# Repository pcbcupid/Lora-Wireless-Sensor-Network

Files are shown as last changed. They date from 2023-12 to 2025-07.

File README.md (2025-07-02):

# Lora-Wireless-Sensor-Network



This repo will teach you, how to build a hardware product based on WSN completely from scratch!

We'll walk you through all the stages : 
* [Purpose](https://www.youtube.com/watch?v=e1ifblb0CRQ)
* [Brainstroming -> Feature Selection](https://www.youtube.com/watch?v=0gfi7CeLzbg)
* [Features -> Component Selection](https://youtu.be/0gfi7CeLzbg?t=293)
* [Component -> Schematic Design](https://www.youtube.com/watch?v=nbiwXsXPYxc)
* [Schematic Design -> PCB Design](https://www.youtube.com/watch?v=FiMsBjr6rtk)
* [PCB -> Mechanical Case Design](https://youtu.be/7FC-pByCCXM?si=cBypyLcrKBF-iJE6)
* [Finished Hardware + Code](https://github.com/pcbcupid/Lora-Wireless-Sensor-Network/tree/main/Code)
* [Final Testing](https://www.youtube.com/watch?v=_qDI99OTmmE)

### PCB DESIGN

###### MASTER NODE 

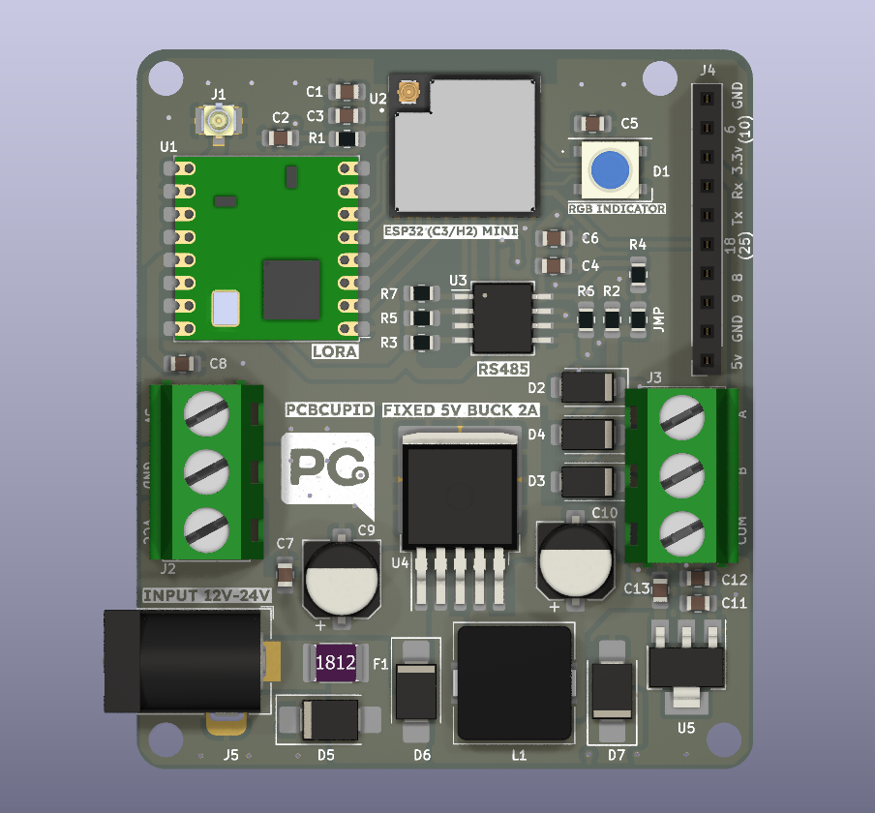
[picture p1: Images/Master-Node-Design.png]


###### SLAVE NODE

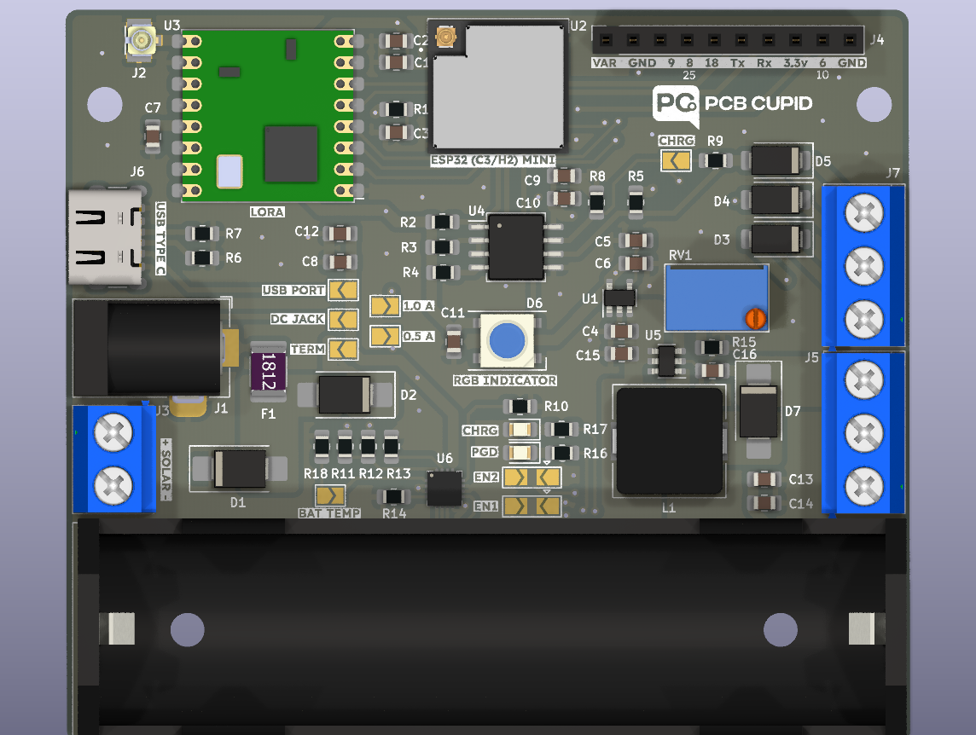
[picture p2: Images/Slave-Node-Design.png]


### PCB ASSEMBLED 

###### MASTER NODE



###### SLAVE NODE 



### CAD DESIGN 

###### MASTER NODE 

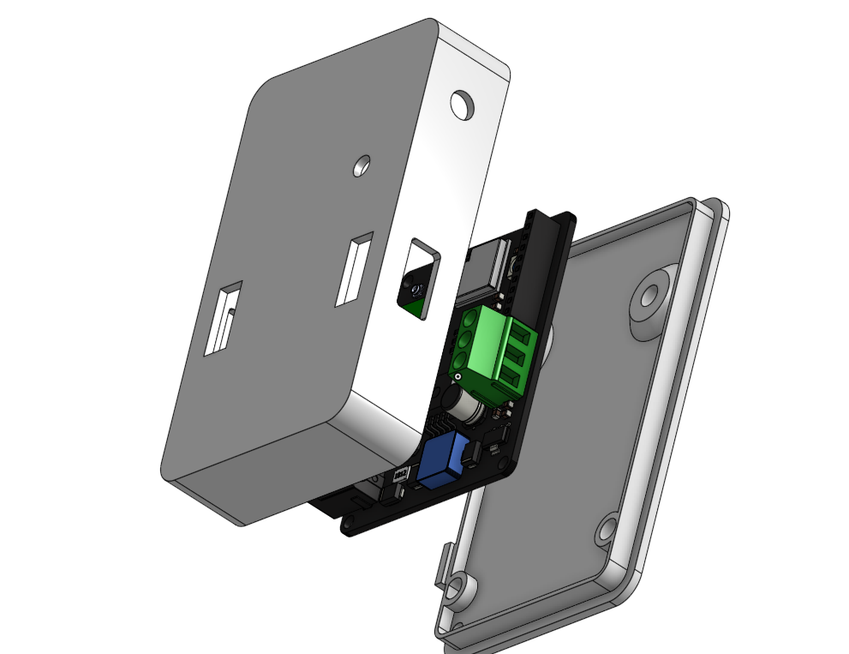
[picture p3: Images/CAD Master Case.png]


###### SLAVE NODE

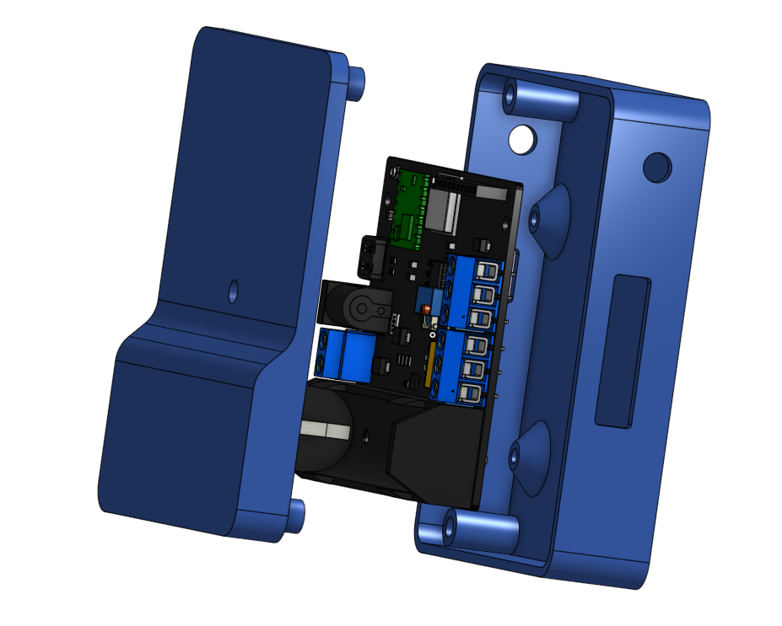
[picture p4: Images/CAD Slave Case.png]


### 3D PRINTING 

###### MASTER NODE CASE 



###### SLAVE NODE CASE



### FINAL SETUP 

###### MASTER NODE SETUP 



###### SLAVE NODE SETUP



### DASHBOARD UI

###### MASTER CLOUD DASHBOARD

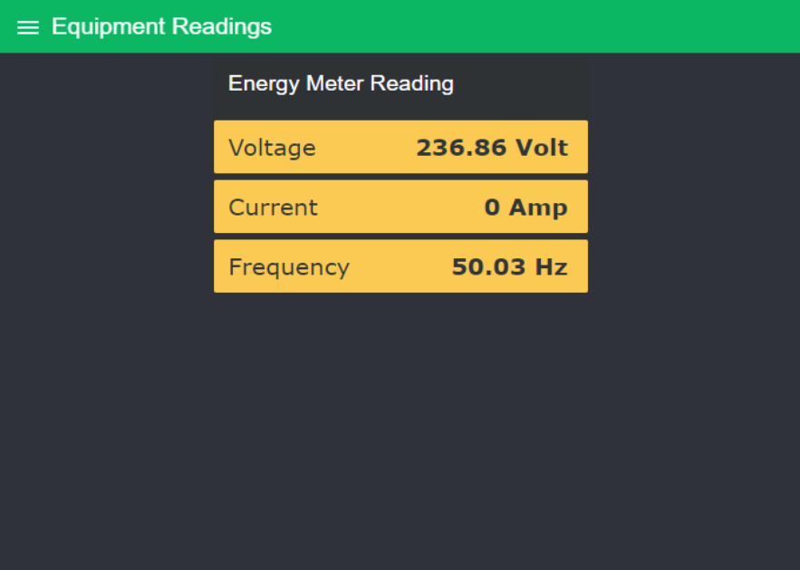
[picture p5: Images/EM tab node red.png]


###### SLAVE CLOUD DASHBOARD

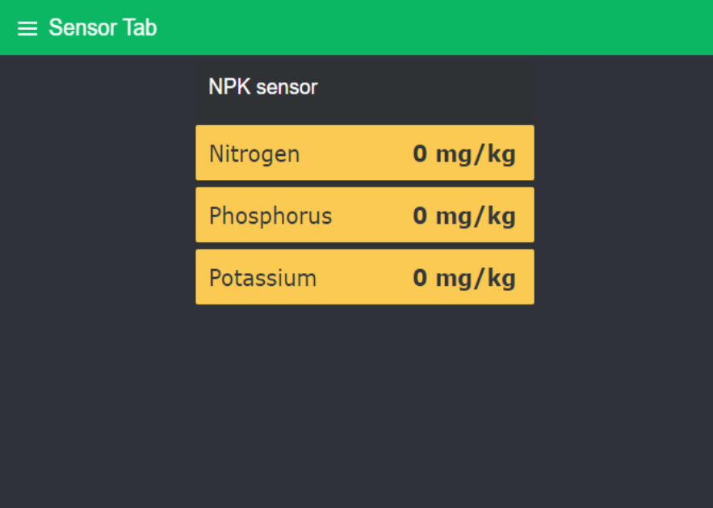
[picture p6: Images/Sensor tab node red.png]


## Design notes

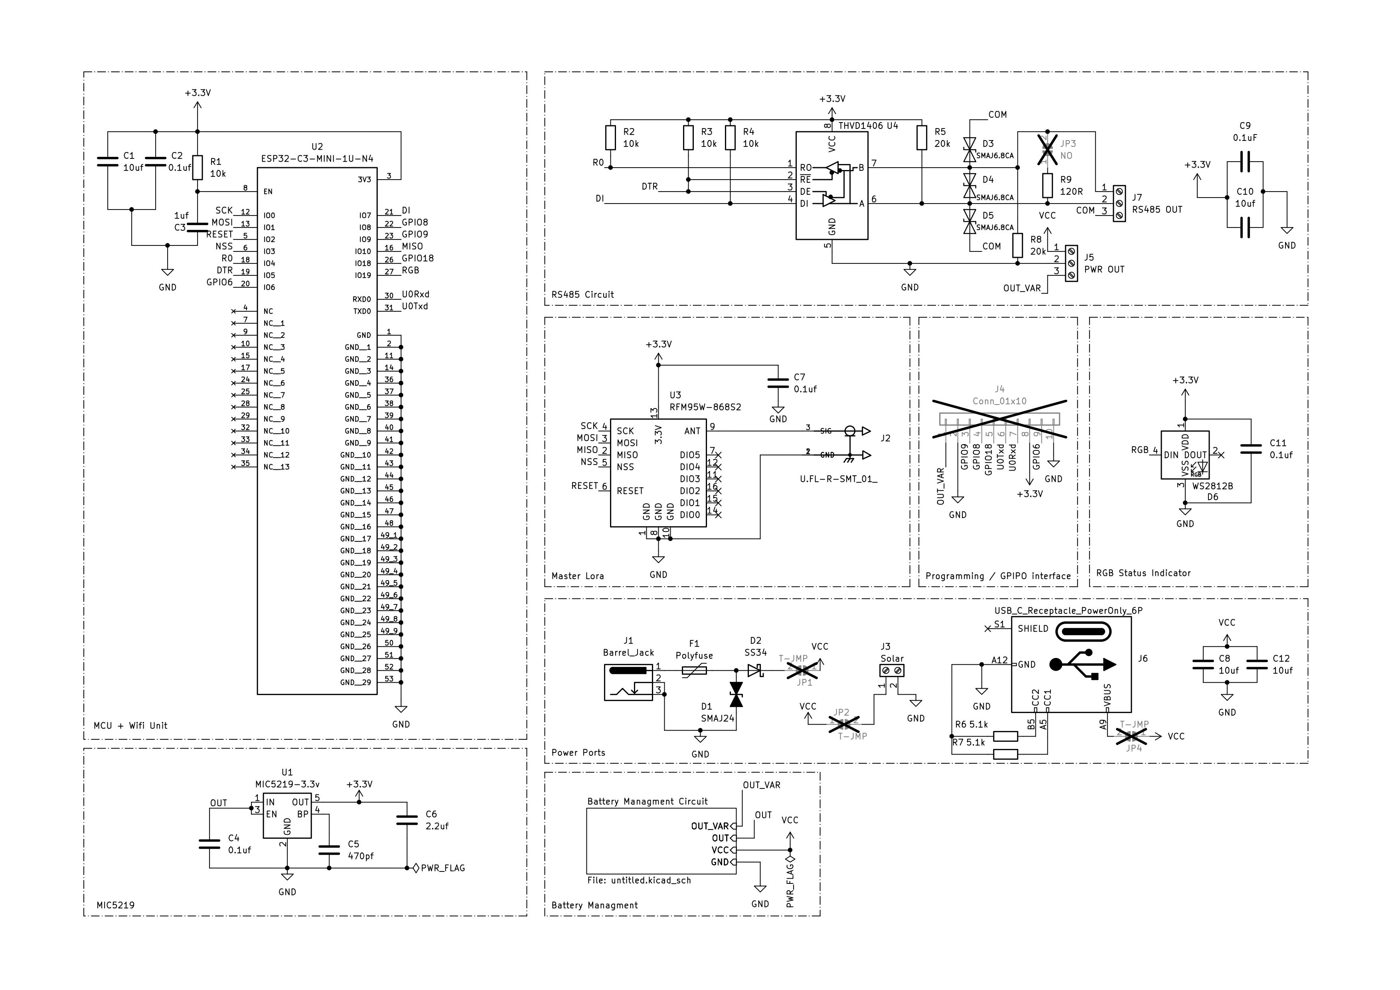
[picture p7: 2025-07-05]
Circuit Diagram/Slave Circuit-1.jpg

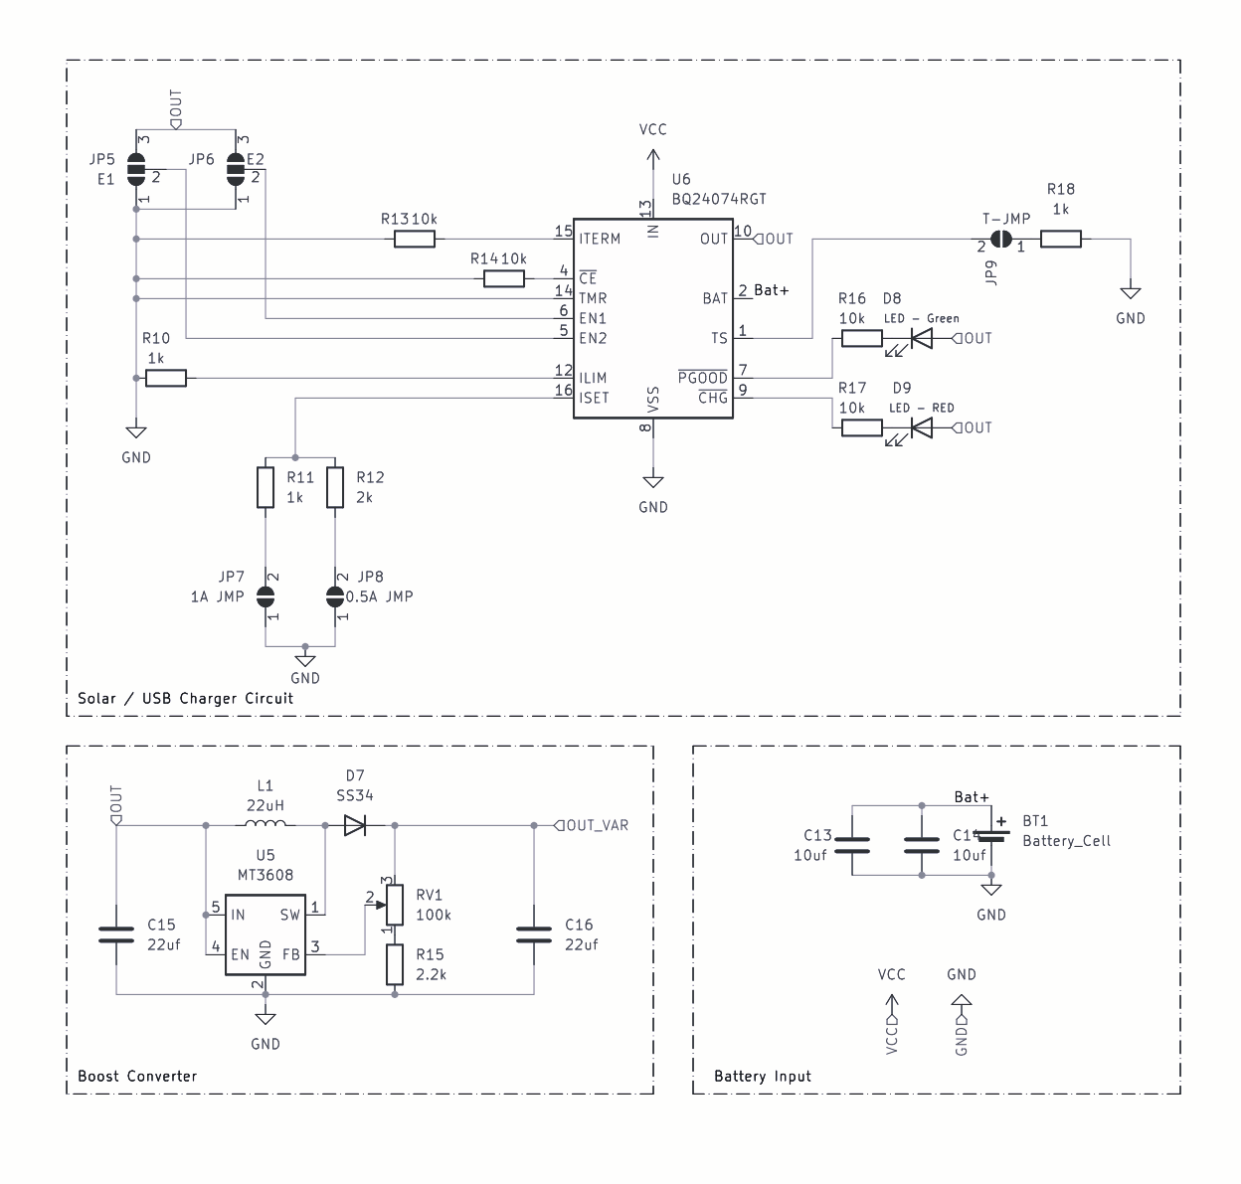
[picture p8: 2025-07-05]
Circuit Diagram/Slave Circuit-2.png

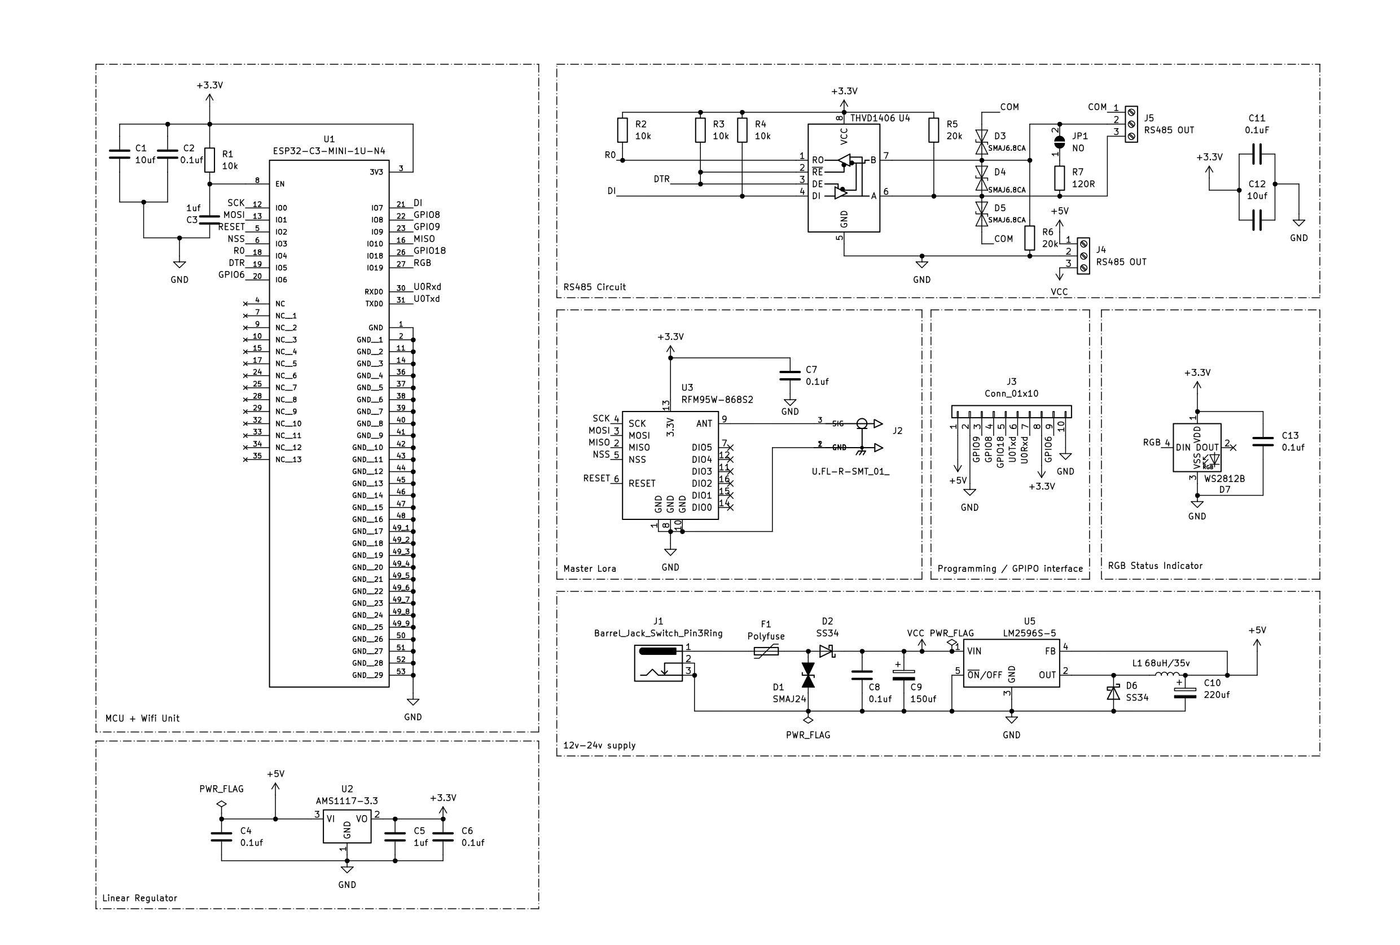
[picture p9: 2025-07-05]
Circuit Diagram/Master Circuit-1.jpg

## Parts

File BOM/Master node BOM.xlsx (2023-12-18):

References | Value | Footprint | Quantity
C1, C5, C6, C7, C8, C12, C13 | 0.1uf | C_0805_2012Metric_Pad1.18x1.45mm_HandSolder | 7
C2, C11 | 1uf | C_0805_2012Metric_Pad1.18x1.45mm_HandSolder | 2
C3, C4 | 10uf | C_0805_2012Metric_Pad1.18x1.45mm_HandSolder | 2
C9 | 150uf | CP_Elec_6.3x7.7 | 1
C10 | 220uf | CP_Elec_6.3x7.7 | 1
R1, R3, R5, R7 | 10k | R_0805_2012Metric_Pad1.20x1.40mm_HandSolder | 4
R2, R6 | 20k | R_0805_2012Metric_Pad1.20x1.40mm_HandSolder | 2
R4 | 120R | R_0805_2012Metric_Pad1.20x1.40mm_HandSolder | 1
L1 | 68uH/35v | L_10.4x10.4_H4.8 | 1
D2, D3, D4 | SMAJ6.8CA | D_SMA | 3
D6, D7 | SS34 | D_SMB_Handsoldering | 2
D1 | WS2812B | LED_WS2812B_PLCC4_5.0x5.0mm_P3.2mm | 1
D5 | SMAJ24 | D_SMB_Handsoldering | 1
U1 | RFM95W-868S2 | HOPERF_RFM9XW_SMD | 1
U2 | ESP32-C3-MINI-1U-N4 | XCVR_ESP32-C3-MINI-1U-N4 | 1
U3 | MAX485E | SO-8_5.3x6.2mm_P1.27mm | 1
U4 | LM2596S-5 | TO-263-5_TabPin3 | 1
U5 | AMS1117-3.3 | SOT-223-3_TabPin2 | 1
F1 | Polyfuse | Fuse_1812_4532Metric_Pad1.30x3.40mm_HandSolder | 1
JMP | NO | R_0805_2012Metric_Pad1.20x1.40mm_HandSolder | 1
J2, J3 | RS485 OUT | TerminalBlock_bornier-3_P5.08mm | 2
J1 | U.FL-R-SMT_01_ | HRS_U.FL-R-SMT_01_ | 1
J4 | Conn_01x10 | PinSocket_1x10_P2.54mm_Vertical | 1
J5 | Barrel_Jack_Switch_Pin3Ring | BarrelJack_Horizontal | 1

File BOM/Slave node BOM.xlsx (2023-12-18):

References | Value | Footprint | Quantity
C1, C8, C10, C12, C13, C14 | 10uf | C_0805_2012Metric_Pad1.18x1.45mm_HandSolder | 6
C2, C4, C7, C9, C11 | 0.1uf | C_0805_2012Metric_Pad1.18x1.45mm_HandSolder | 5
C15, C16 | 22uf | C_0805_2012Metric_Pad1.18x1.45mm_HandSolder | 2
C3 | 1uf | C_0805_2012Metric_Pad1.18x1.45mm_HandSolder | 1
C5 | 470pf | C_0805_2012Metric_Pad1.18x1.45mm_HandSolder | 1
C6 | 2.2uf | C_0805_2012Metric_Pad1.18x1.45mm_HandSolder | 1
R1, R2, R3, R4, R13, R14, R16, R17 | 10k | R_0805_2012Metric_Pad1.20x1.40mm_HandSolder | 8
R10, R11, R18 | 1k | R_0805_2012Metric_Pad1.20x1.40mm_HandSolder | 3
R5, R8 | 20k | R_0805_2012Metric_Pad1.20x1.40mm_HandSolder | 2
R6, R7 | 5.1k | R_0805_2012Metric_Pad1.20x1.40mm_HandSolder | 2
R9 | 120R | R_0805_2012Metric_Pad1.20x1.40mm_HandSolder | 1
R12 | 2k | R_0805_2012Metric_Pad1.20x1.40mm_HandSolder | 1
R15 | 2.2k | R_0805_2012Metric_Pad1.20x1.40mm_HandSolder | 1
L1 | L | L_10.4x10.4_H4.8 | 1
D3, D4, D5 | SMAJ6.8CA | D_SMA | 3
D1 | SMAJ24 | D_SMB_Handsoldering | 1
D2 | SS34 | D_SMB_Handsoldering | 1
D6 | WS2812B | LED_WS2812B_PLCC4_5.0x5.0mm_P3.2mm | 1
D7 | D | D_SMB_Handsoldering | 1
D8 | LED - Green | LED_0805_2012Metric_Pad1.15x1.40mm_HandSolder | 1
D9 | LED - RED | LED_0805_2012Metric_Pad1.15x1.40mm_HandSolder | 1
U1 | MIC5219-3.3v | SOT-23-5 | 1
U2 | ESP32-C3-MINI-1U-N4 | XCVR_ESP32-C3-MINI-1U-N4 | 1
U3 | RFM95W-868S2 | HOPERF_RFM9XW_SMD | 1
U4 | MAX485E | SO-8_5.3x6.2mm_P1.27mm | 1
U5 | MT3608 | SOT-23-6 | 1
U6 | BQ24074RGT | VQFN-16-1EP_3x3mm_P0.5mm_EP1.6x1.6mm | 1
F1 | Polyfuse | Fuse_1812_4532Metric_Pad1.30x3.40mm_HandSolder | 1
JP1, JP2, JP4, JP9 | T-JMP | SolderJumper-2_P1.3mm_Open_TrianglePad1.0x1.5mm | 4
BT1 | Battery_Cell | BatteryHolder_MPD_BH-18650-PC2 | 1
JP3 | NO | SolderJumper-2_P1.3mm_Open_TrianglePad1.0x1.5mm | 1
JP5 | E1 | SolderJumper-3_P2.0mm_Open_TrianglePad1.0x1.5mm | 1
JP6 | E2 | SolderJumper-3_P2.0mm_Open_TrianglePad1.0x1.5mm | 1
JP7 | 1A JMP | SolderJumper-2_P1.3mm_Open_TrianglePad1.0x1.5mm | 1
JP8 | 0.5A JMP | SolderJumper-2_P1.3mm_Open_TrianglePad1.0x1.5mm | 1
RV1 | 100k | Potentiometer_Bourns_3299W_Vertical | 1
J1 | Barrel_Jack | BarrelJack_Horizontal | 1
J2 | U.FL-R-SMT_01_ | HRS_U.FL-R-SMT_01_ | 1
J3 | Solar | TerminalBlock_bornier-2_P5.08mm | 1
J4 | Conn_01x10 | PinSocket_1x10_P2.54mm_Vertical | 1
J5 | PWR OUT | TerminalBlock_bornier-3_P5.08mm | 1
J6 | USB_C_Receptacle_PowerOnly_6P | USB_C_Receptacle_GCT_USB4125-xx-x_6P_TopMnt_Horizontal | 1
J7 | RS485 OUT | TerminalBlock_bornier-3_P5.08mm | 1

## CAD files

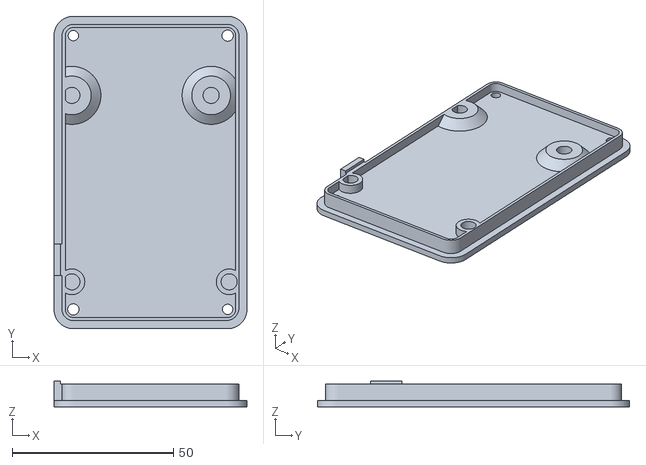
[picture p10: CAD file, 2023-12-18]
3D models/Master Bottom v3.stl
59.8 x 96.9 x 7.95

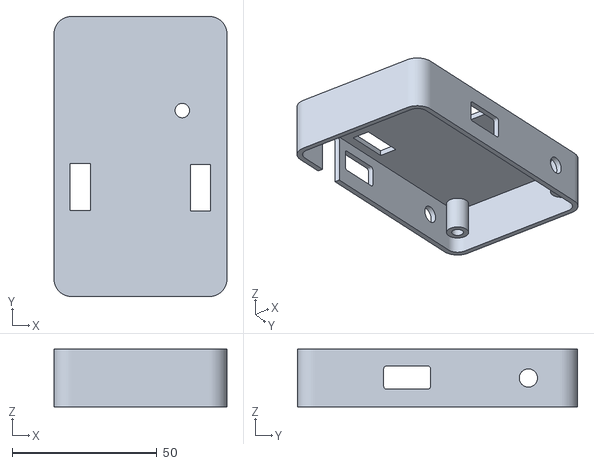
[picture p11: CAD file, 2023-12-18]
3D models/Master Top_v3.stl
59.8 x 96.9 x 20.0

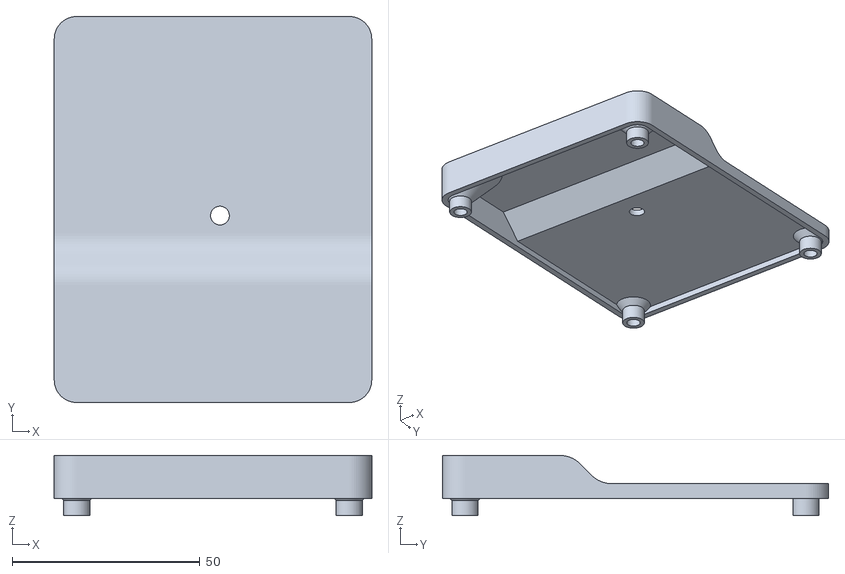
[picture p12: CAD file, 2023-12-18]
3D models/Slave Top_v3.stl
84.6 x 102.8 x 16.0

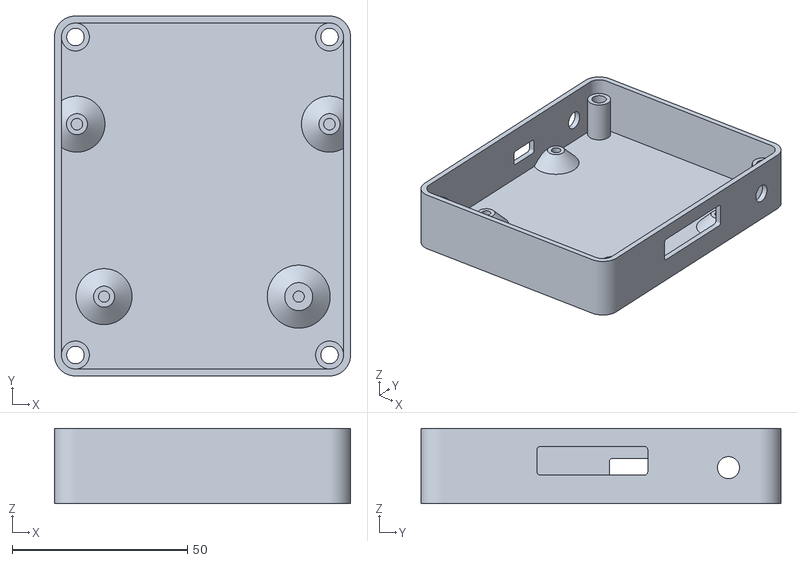
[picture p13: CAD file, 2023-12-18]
3D models/Slave Base_v3.stl
84.6 x 102.8 x 21.5

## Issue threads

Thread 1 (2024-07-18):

MAX485 Voltage

rajtan, 2024-07-18:
Hi, Your project oon LoRa WSN is great and well planned.

However, I had one apprehension that you have used MAX485 and intterfaced it with ESP32. Would it not be an issue as the nominal working voltage for MAX485 is 5V and in order to ensure safety you have tied it up with 3V rail (fine) but would this not affect the proper working of MAX transceirver? Would it be more appropriate to use MAX3485 (with appropriate foorprint and package of course)

Neutrino-1, 2025-07-05:
Thanks for pointing it out! Not sure what I was thinking when I used MAX485, but now I have replaced it with THVD1406 from Texas Instruments.

Which is pin to pin compatible and have same footprint. So, I don't have to change the schematic (just updated the BOM) or the layout.

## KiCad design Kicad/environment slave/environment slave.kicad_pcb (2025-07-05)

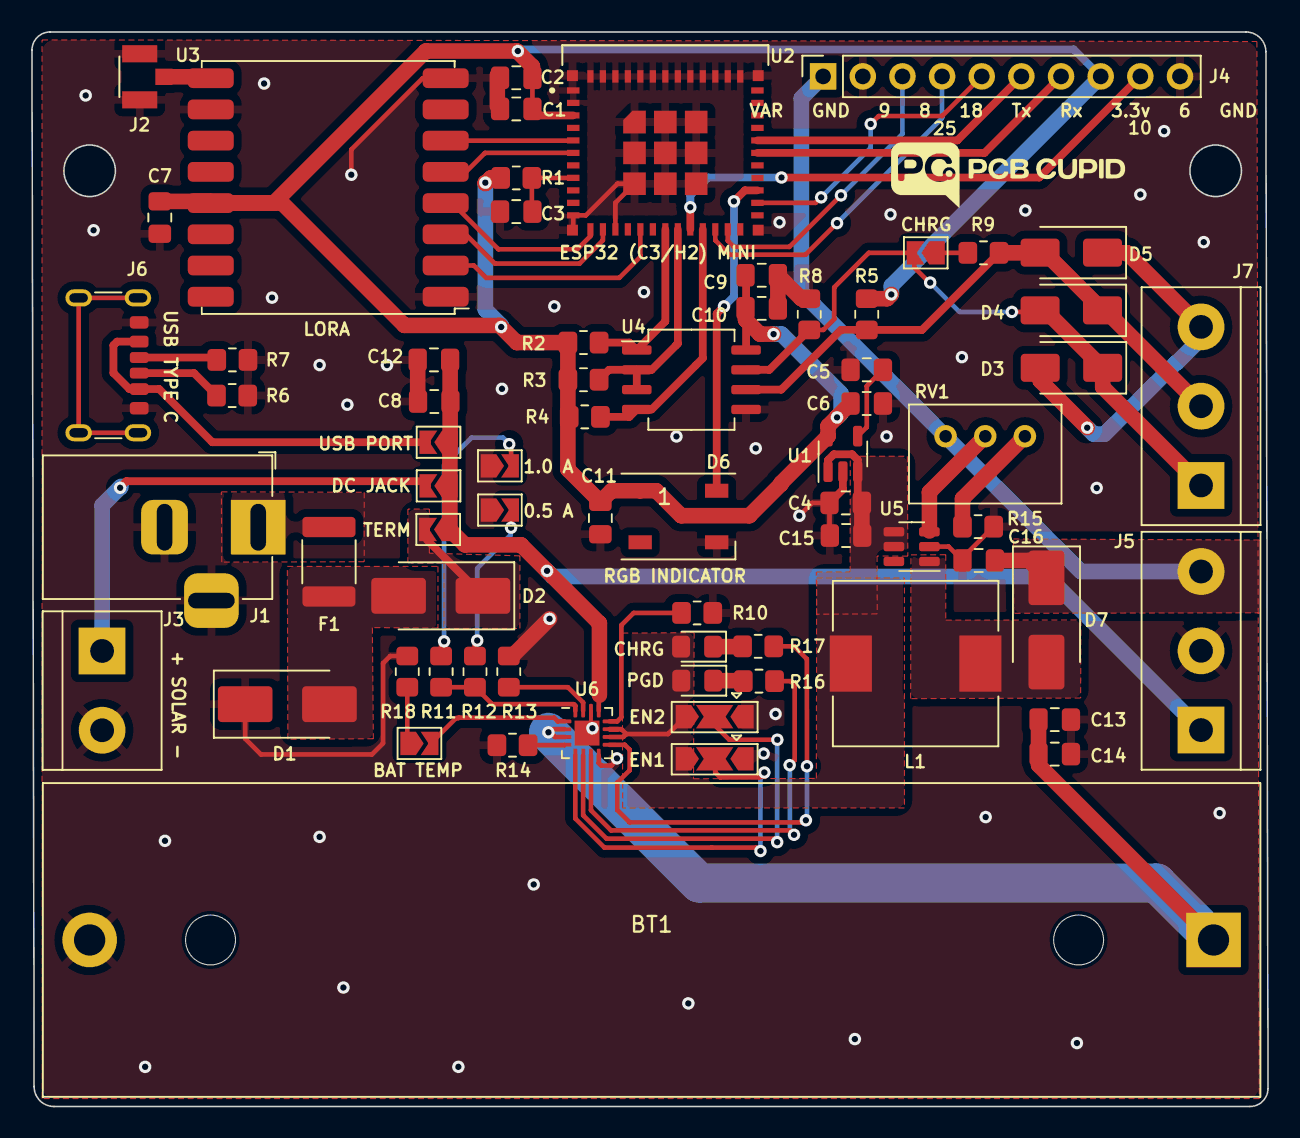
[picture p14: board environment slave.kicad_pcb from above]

Board: 2 copper layers, 79.2 x 68.8 mm, 69 parts (0 on the bottom side), 52 nets.

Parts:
BT1: Battery_Cell; BatteryHolder_MPD_BH-18650-PC2
C1, C8, C10, C12, C13, C14: 10uf; C_0805_2012Metric_Pad1.18x1.45mm_HandSolder
C2, C4, C7, C11: 0.1uf; C_0805_2012Metric_Pad1.18x1.45mm_HandSolder
C3: 1uf; C_0805_2012Metric_Pad1.18x1.45mm_HandSolder
C5: 470pf; C_0805_2012Metric_Pad1.18x1.45mm_HandSolder
C6: 2.2uf; C_0805_2012Metric_Pad1.18x1.45mm_HandSolder
C9: 0.1uF; C_0805_2012Metric_Pad1.18x1.45mm_HandSolder
C15, C16: 22uf; C_0805_2012Metric_Pad1.18x1.45mm_HandSolder
D1: SMAJ24; D_SMB_Handsoldering
D2: SS34; D_SMB_Handsoldering
D3, D4, D5: SMAJ6.8CA; D_SMA
D6: WS2812B; LED_WS2812B_PLCC4_5.0x5.0mm_P3.2mm
D7: D; D_SMB_Handsoldering
D8: LED - Green; LED_0805_2012Metric_Pad1.15x1.40mm_HandSolder
D9: LED - RED; LED_0805_2012Metric_Pad1.15x1.40mm_HandSolder
F1: Polyfuse; Fuse_1812_4532Metric_Pad1.30x3.40mm_HandSolder
J1: Barrel_Jack; BarrelJack_Horizontal
J2: U.FL-R-SMT_01_; HRS_U.FL-R-SMT_01_
J3: Solar; TerminalBlock_bornier-2_P5.08mm
J4: Conn_01x10; PinSocket_1x10_P2.54mm_Vertical
J5: PWR OUT; TerminalBlock_bornier-3_P5.08mm
J6: USB_C_Receptacle_PowerOnly_6P; USB_C_Receptacle_GCT_USB4125-xx-x_6P_TopMnt_Horizontal
J7: RS485 OUT; TerminalBlock_bornier-3_P5.08mm
JP1, JP2, JP4, JP9: T-JMP; SolderJumper-2_P1.3mm_Open_TrianglePad1.0x1.5mm
JP3: NO; SolderJumper-2_P1.3mm_Open_TrianglePad1.0x1.5mm
JP5: E1; SolderJumper-3_P2.0mm_Open_TrianglePad1.0x1.5mm
JP6: E2; SolderJumper-3_P2.0mm_Open_TrianglePad1.0x1.5mm
JP7: 1A JMP; SolderJumper-2_P1.3mm_Open_TrianglePad1.0x1.5mm
JP8: 0.5A JMP; SolderJumper-2_P1.3mm_Open_TrianglePad1.0x1.5mm
L1: L; L_10.4x10.4_H4.8
R1, R2, R3, R4, R13, R14, R16, R17: 10k; R_0805_2012Metric_Pad1.20x1.40mm_HandSolder
R5, R8: 20k; R_0805_2012Metric_Pad1.20x1.40mm_HandSolder
R6, R7: 5.1k; R_0805_2012Metric_Pad1.20x1.40mm_HandSolder
R9: 120R; R_0805_2012Metric_Pad1.20x1.40mm_HandSolder
R10, R11, R18: 1k; R_0805_2012Metric_Pad1.20x1.40mm_HandSolder
R12: 2k; R_0805_2012Metric_Pad1.20x1.40mm_HandSolder
R15: 2.2k; R_0805_2012Metric_Pad1.20x1.40mm_HandSolder
RV1: 100k; Potentiometer_Bourns_3299W_Vertical
U1: MIC5219-3.3v; SOT-23-5
U2: ESP32-C3-MINI-1U-N4; XCVR_ESP32-C3-MINI-1U-N4
U3: RFM95W-868S2; HOPERF_RFM9XW_SMD
U4: THVD1406; SO-8_5.3x6.2mm_P1.27mm
U5: MT3608; SOT-23-6
U6: BQ24074RGT; VQFN-16-1EP_3x3mm_P0.5mm_EP1.6x1.6mm

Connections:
+3.3V: C1.1, C2.1, C6.1, C7.1, C9.1, C10.1, C11.1, D6.1 (VDD), J4.8, R1.1, R2.1, R3.1, R4.1, R5.1, U1.5 (OUT), U2.3 (3V3), U3.13 (3.3V), U4.8 (VCC)
/Battery Managment Circuit/Bat+: BT1.1 (+), C13.1, C14.1, U6.2 (BAT), U6.3 (BAT)
/COM: D3.2 (A2), D5.1 (A1), J7.3
/DI: R4.2, U2.21 (IO7), U4.4 (DI)
/DTR: R3.2, U2.19 (IO5), U4.2 (~RE), U4.3 (DE)
/GPIO6: J4.9, U2.20 (IO6)
/GPIO8: J4.4, U2.22 (IO8)
/GPIO9: J4.3, U2.23 (IO9)
/GPIO18: J4.5, U2.26 (IO18)
/MISO: U2.16 (IO10), U3.2 (MISO)
/MOSI: U2.13 (IO1), U3.3 (MOSI)
/NSS: U2.6 (IO3), U3.5 (NSS)
/OUT: C4.1, C15.1, D8.2 (A), D9.2 (A), JP5.3 (B), JP6.3 (B), L1.1, U1.1 (IN), U1.3 (EN), U5.4 (EN), U5.5 (IN), U6.10 (OUT), U6.11 (OUT)
/OUT_VAR: C16.1, D7.1 (K), J4.1, J5.3, RV1.3
/R0: R2.2, U2.18 (IO4), U4.1 (RO)
/RESET: U2.5 (IO2), U3.6 (RESET)
/RGB: D6.4 (DIN), U2.27 (IO19)
/SCK: U2.12 (IO0), U3.4 (SCK)
/U0Rxd: J4.7, U2.30 (RXD0)
/U0Txd: J4.6, U2.31 (TXD0)
GND: BT1.2 (-), C1.2, C2.2, C3.2, C4.2, C5.2, C6.2, C7.2, C8.2, C9.2, C10.2, C11.2, C12.2, C13.2, C14.2, C15.2, C16.2, D1.1 (A1), D6.3 (VSS), J1.2, J1.3, J2.1 (GND), J2.2 (GND), J3.2, J4.2, J4.10, J5.2, J6.A12 (GND), J6.B12 (GND), JP5.1 (A), JP6.1 (A), JP7.1 (A), JP8.1 (A), R6.1, R7.1, R8.2, R10.1, R13.1, R14.1, R15.2, R18.2, U1.2 (GND), U2.1 (GND), U2.2 (GND__1), U2.11 (GND__2), U2.14 (GND__3), U2.36 (GND__4), U2.37 (GND__5), U2.38 (GND__6), U2.39 (GND__7), U2.40 (GND__8), U2.41 (GND__9), U2.42 (GND__10), U2.43 (GND__11), U2.44 (GND__12), U2.45 (GND__13), U2.46 (GND__14), U2.47 (GND__15), U2.48 (GND__16), U2.49_1 (GND__17), U2.49_2 (GND__18), U2.49_3 (GND__19), U2.49_4 (GND__20), U2.49_5 (GND__21), U2.49_6 (GND__22), U2.49_7 (GND__23), U2.49_8 (GND__24), U2.49_9 (GND__25), U2.50 (GND__26), U2.51 (GND__27), U2.52 (GND__28), U2.53 (GND__29), U3.1 (GND), U3.8 (GND), U3.10 (GND), U4.5 (GND), U5.2 (GND), U6.8 (VSS), U6.14 (TMR), U6.17 (VSS)
unnamed: D1.2 (A2), D2.2 (A), F1.2
unnamed: D2.1 (K), JP1.2 (B)
unnamed: D3.1 (A1), D4.2 (A2), J7.1, JP3.2 (B), R8.1, U4.7 (B)
unnamed: D4.1 (A1), D5.2 (A2), J7.2, R5.2, R9.2, U4.6 (A)
unnamed: D7.2 (A), L1.2, U5.1 (SW)
unnamed: D8.1 (K), R16.2
unnamed: D9.1 (K), R17.2
unnamed: F1.1, J1.1
unnamed: J2.3 (SIG), U3.9 (ANT)
unnamed: J3.1, JP2.2 (B)
unnamed: J6.A5 (CC1), R7.2
unnamed: J6.B5 (CC2), R6.2
unnamed: JP3.1 (A), R9.1
unnamed: J6.A9 (VBUS), J6.B9 (VBUS), JP4.2 (B)
unnamed: JP5.2 (C), U6.5 (EN2)
unnamed: JP6.2 (C), U6.6 (EN1)
unnamed: JP7.2 (B), R11.1
unnamed: JP8.2 (B), R12.1
unnamed: JP9.1 (A), R18.1
unnamed: JP9.2 (B), U6.1 (TS)
unnamed: R15.1, RV1.1
unnamed: C5.1, U1.4 (BP)
unnamed: C3.1, R1.2, U2.8 (EN)
unnamed: RV1.2, U5.3 (FB)
unnamed: R10.2, U6.12 (ILIM)
unnamed: R11.2, R12.2, U6.16 (ISET)
unnamed: R13.2, U6.15 (ITERM)
unnamed: R14.2, U6.4 (~CE)
unnamed: R17.1, U6.9 (~CHG)
unnamed: R16.1, U6.7 (~PGOOD)
VCC: C8.1, C12.1, J5.1, JP1.1 (A), JP2.1 (A), JP4.1 (A), U6.13 (IN)

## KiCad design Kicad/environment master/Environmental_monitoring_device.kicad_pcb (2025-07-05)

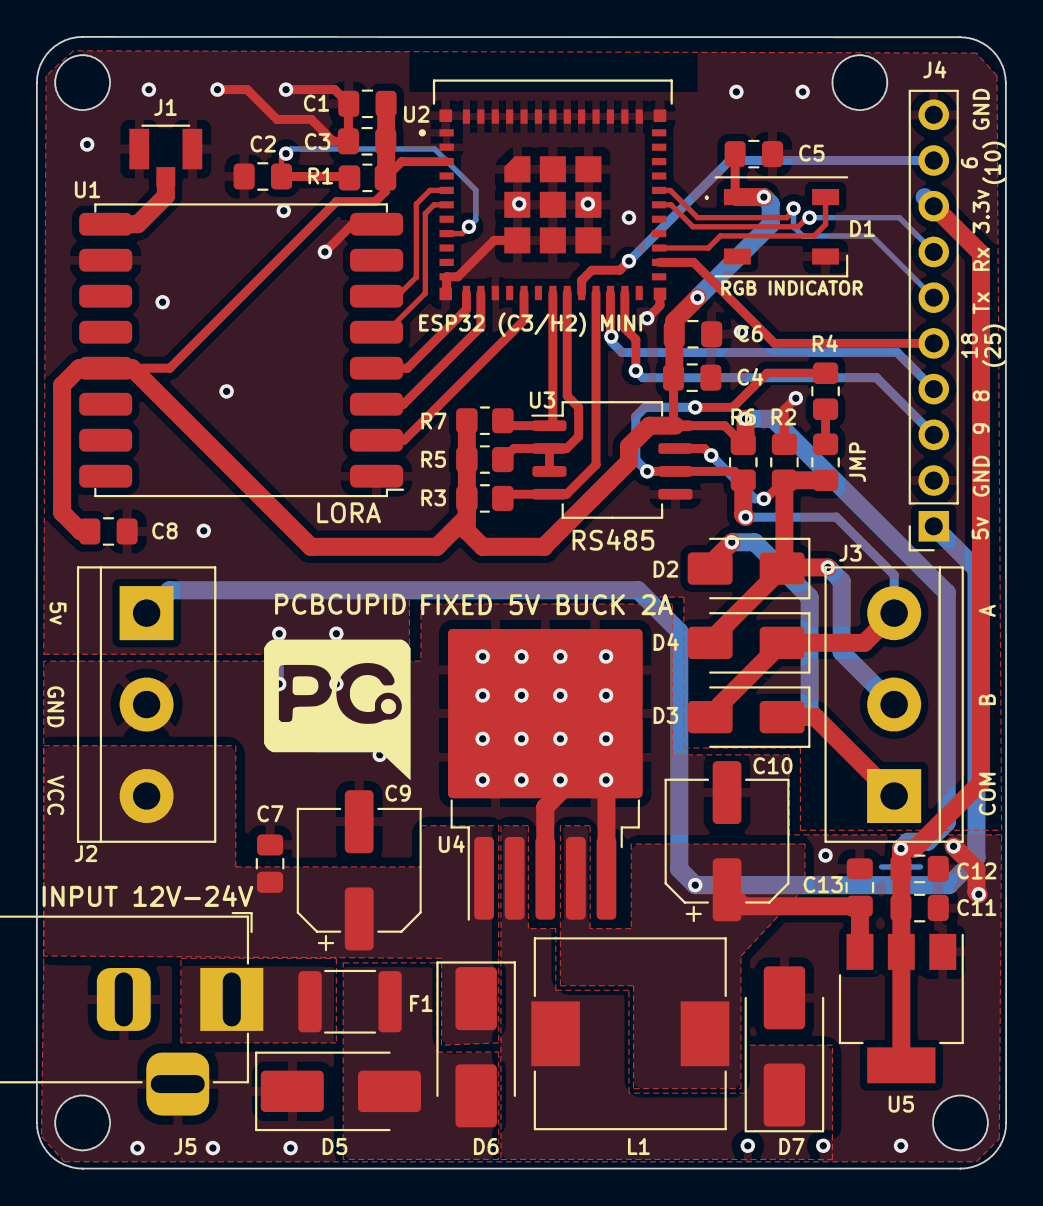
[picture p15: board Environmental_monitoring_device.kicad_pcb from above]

Board: 2 copper layers, 53.8 x 62.9 mm, 40 parts (0 on the bottom side), 28 nets.

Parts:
C1, C5, C7, C8, C12, C13: 0.1uf; C_0805_2012Metric_Pad1.18x1.45mm_HandSolder
C2, C11: 1uf; C_0805_2012Metric_Pad1.18x1.45mm_HandSolder
C3, C4: 10uf; C_0805_2012Metric_Pad1.18x1.45mm_HandSolder
C6: 0.1uF; C_0805_2012Metric_Pad1.18x1.45mm_HandSolder
C9: 150uf; CP_Elec_6.3x7.7
C10: 220uf; CP_Elec_6.3x7.7
D1: WS2812B; LED_WS2812B_PLCC4_5.0x5.0mm_P3.2mm
D2, D3, D4: SMAJ6.8CA; D_SMA
D5: SMAJ24; D_SMB_Handsoldering
D6, D7: SS34; D_SMB_Handsoldering
F1: Polyfuse; Fuse_1812_4532Metric_Pad1.30x3.40mm_HandSolder
J1: U.FL-R-SMT_01_; HRS_U.FL-R-SMT_01_
J2, J3: RS485 OUT; TerminalBlock_bornier-3_P5.08mm
J4: Conn_01x10; PinSocket_1x10_P2.54mm_Vertical
J5: Barrel_Jack_Switch_Pin3Ring; BarrelJack_Horizontal
JMP: NO; R_0805_2012Metric_Pad1.20x1.40mm_HandSolder
L1: 68uH/35v; L_10.4x10.4_H4.8
R1, R3, R5, R7: 10k; R_0805_2012Metric_Pad1.20x1.40mm_HandSolder
R2, R6: 20k; R_0805_2012Metric_Pad1.20x1.40mm_HandSolder
R4: 120R; R_0805_2012Metric_Pad1.20x1.40mm_HandSolder
U1: RFM95W-868S2; HOPERF_RFM9XW_SMD
U2: ESP32-C3-MINI-1U-N4; XCVR_ESP32-C3-MINI-1U-N4
U3: THVD1406; SO-8_5.3x6.2mm_P1.27mm
U4: LM2596S-5; TO-263-5_TabPin3
U5: AMS1117-3.3; SOT-223-3_TabPin2

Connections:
+3.3V: C1.1, C3.1, C4.1, C5.1, C6.1, C8.1, C11.1, C12.1, D1.1 (VDD), J4.8, R1.1, R3.1, R5.1, R6.1, R7.1, U1.13 (3.3V), U2.3 (3V3), U3.8 (VCC), U5.2 (VO)
+5V: C10.1, C13.1, J2.1, J4.1, L1.2, U4.4 (FB), U5.3 (VI)
/COM: D2.2 (A2), D3.1 (A1), J3.1
/DI: R3.2, U2.21 (IO7), U3.4 (DI)
/DTR: R5.2, U2.19 (IO5), U3.2 (~RE), U3.3 (DE)
/GPIO6: J4.9, U2.20 (IO6)
/GPIO8: J4.4, U2.22 (IO8)
/GPIO9: J4.3, U2.23 (IO9)
/GPIO18: J4.5, U2.26 (IO18)
/MISO: U1.2 (MISO), U2.16 (IO10)
/MOSI: U1.3 (MOSI), U2.13 (IO1)
/NSS: U1.5 (NSS), U2.6 (IO3)
/R0: R7.2, U2.18 (IO4), U3.1 (RO)
/RESET: U1.6 (RESET), U2.5 (IO2)
/RGB: D1.4 (DIN), U2.27 (IO19)
/SCK: U1.4 (SCK), U2.12 (IO0)
/U0Rxd: J4.7, U2.30 (RXD0)
/U0Txd: J4.6, U2.31 (TXD0)
GND: C1.2, C2.2, C3.2, C4.2, C5.2, C6.2, C7.2, C8.2, C9.2, C10.2, C11.2, C12.2, C13.2, D1.3 (VSS), D5.1 (A1), D7.2 (A), J1.1 (GND), J1.2 (GND), J2.2, J4.2, J4.10, J5.2, J5.3, R2.2, U1.1 (GND), U1.8 (GND), U1.10 (GND), U2.1 (GND), U2.2 (GND__1), U2.11 (GND__2), U2.14 (GND__3), U2.36 (GND__4), U2.37 (GND__5), U2.38 (GND__6), U2.39 (GND__7), U2.40 (GND__8), U2.41 (GND__9), U2.42 (GND__10), U2.43 (GND__11), U2.44 (GND__12), U2.45 (GND__13), U2.46 (GND__14), U2.47 (GND__15), U2.48 (GND__16), U2.49_1 (GND__17), U2.49_2 (GND__18), U2.49_3 (GND__19), U2.49_4 (GND__20), U2.49_5 (GND__21), U2.49_6 (GND__22), U2.49_7 (GND__23), U2.49_8 (GND__24), U2.49_9 (GND__25), U2.50 (GND__26), U2.51 (GND__27), U2.52 (GND__28), U2.53 (GND__29), U3.5 (GND), U4.3 (GND), U4.5 (~ON/OFF), U5.1 (GND)
unnamed: D5.2 (A2), D6.2 (A), F1.2
unnamed: D2.1 (A1), D4.2 (A2), J3.2, JMP.2 (B), R2.1, U3.7 (B)
unnamed: D3.2 (A2), D4.1 (A1), J3.3, R4.2, R6.2, U3.6 (A)
unnamed: D7.1 (K), L1.1, U4.2 (OUT)
unnamed: F1.1, J5.1
unnamed: J1.3 (SIG), U1.9 (ANT)
unnamed: JMP.1 (A), R4.1
unnamed: C2.1, R1.2, U2.8 (EN)
VCC: C7.1, C9.1, D6.1 (K), J2.3, U4.1 (VIN)

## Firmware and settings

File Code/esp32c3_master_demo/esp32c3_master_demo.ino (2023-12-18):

#include <WiFi.h>
#include <PubSubClient.h>
// To Run the RS485
#include <SoftwareSerial.h>
// Energy Meter uses Modbus protocol
#include <ModbusMaster.h>
// To Run Lora
#include <SPI.h>
#include <LoRa.h>

// RGB LED Control
#include <Adafruit_NeoPixel.h>

// To Package sensor data
#include <ArduinoJson.h>

//Lora SPI Pin configuration
#define SS 3
#define RST 2
#define DIO 6

#define DTR 5

// Replace the next variables with your SSID/Password combination
const char* ssid = "Airtel_Internet";
const char* password = "@werty2398";

const char* mqtt_server = "165.232.185.212";

WiFiClient espClient;
PubSubClient client(espClient);
long lastMsg = 0;
char msg[50];
int value = 0;

Adafruit_NeoPixel pixels(1, 19, NEO_GRB + NEO_KHZ800);
SoftwareSerial emSerial(4, 7);
ModbusMaster emNode;

StaticJsonDocument<128> doc;

void setup() {
  //Serial setup
  Serial.begin(115200);

  // Modbus for energy meter setup

  pinMode(DTR, OUTPUT);
  digitalWrite(DTR, LOW);

  emSerial.begin(9600, EspSoftwareSerial::SWSERIAL_8E1);
  emNode.begin(1, emSerial);

  //  callbacks allow us to configure the RS485 transceiver correctly
  emNode.preTransmission(modbusPreTransmission);
  emNode.postTransmission(modbusPostTransmission);

  pixels.begin();
  pixels.clear();

  LoRa.setPins(SS, RST, DIO);  // set CS, reset, IRQ pin

  if (!LoRa.begin(868E6)) {  // initialize ratio at 868 MHz
    Serial.println("LoRa init failed. Check your connections.");
    while (true)
      ;  // if failed, do nothing
  }

  setup_wifi();
  client.setServer(mqtt_server, 1883);
}

void loop() {
  // put your main code here, to run repeatedly:
  // try to parse packet
  int packetSize = LoRa.parsePacket();
  String input = "";

  if (!client.connected()) {
    reconnect();
  }
  client.loop();

  if (packetSize) {
    // received a packet
    Serial.print("Received packet'");

    // read packet
    while (LoRa.available()) {
      input = LoRa.readString();
      Serial.println(input);
    }

    // print RSSI of packet
    Serial.print("' with RSSI ");
    int rssi = LoRa.packetRssi();
    int RGBbrigtness = map(abs(rssi),100,20,10,100);
    Serial.println(rssi);

    

    DeserializationError error = deserializeJson(doc, input);

    if (error) {
      Serial.print("deserializeJson() failed: ");
      Serial.println(error.c_str());
      return;
    }

    float nitro = doc["nitro"];
    float phos = doc["phos"];
    float pot = doc["pot"];
    int R = doc["R"];
    int G = doc["G"];
    int B = doc["B"];

    float voltage = emRead(109);
    float current = emRead(121);
    float frequency = emRead(171);

    Serial.printf("EM reading -> Voltage : %f Current : %f Frequency %f ", voltage, current, frequency);
    Serial.println();

    pixels.setPixelColor(0, pixels.Color(R, G, B));
    pixels.setBrightness(RGBbrigtness);
    pixels.show();  // Send the updated pixel colors to the hardware.
    
    char tempString[8];//temprory String
    //publish the data to mqtt
    dtostrf(nitro, 1, 2, tempString);
    client.publish("n", tempString);
    
    dtostrf(phos, 1, 2, tempString);
    client.publish("p", tempString);
    
    dtostrf(pot, 1, 2, tempString);
    client.publish("k", tempString);

    dtostrf(voltage, 1, 2, tempString);
    client.publish("v",tempString);

    dtostrf(current, 1, 2, tempString);
    client.publish("c", tempString);
    
    dtostrf(frequency, 1, 2, tempString);
    client.publish("f", tempString);
  }
}

void setup_wifi() {
  delay(10);
  // We start by connecting to a WiFi network
  Serial.println();
  Serial.print("Connecting to ");
  Serial.println(ssid);

  WiFi.begin(ssid, password);

  while (WiFi.status() != WL_CONNECTED) {
    delay(500);
    Serial.print(".");
  }

  Serial.println("");
  Serial.println("WiFi connected");
  Serial.println("IP address: ");
  Serial.println(WiFi.localIP());
}

void reconnect() {
  // Loop until we're reconnected
  while (!client.connected()) {
    Serial.print("Attempting MQTT connection...");
    // Attempt to connect
    if (client.connect("MasterNode","sara","digital2Ocean")) {
      Serial.println("connected");
    } else {
      Serial.print("failed, rc=");
      Serial.print(client.state());
      Serial.println(" try again in 5 seconds");
      // Wait 5 seconds before retrying
      delay(5000);
    }
  }
}

// Pin 5 made high for Modbus transmision mode
void modbusPreTransmission() {
  delay(500);
  digitalWrite(DTR, HIGH);
}
// Pin 5 made low for Modbus receive mode
void modbusPostTransmission() {
  digitalWrite(DTR, LOW);
  delay(500);
}

float emRead(uint16_t ra) {
  uint16_t data[2];
  float reading = 0.0;

  uint8_t result = emNode.readHoldingRegisters(ra, 2);
  if (result == emNode.ku8MBSuccess) {
    data[0] = emNode.getResponseBuffer(0x00);
    data[1] = emNode.getResponseBuffer(0x01);
    reading = *((float*)data);
    emNode.clearResponseBuffer();
  } else {
    Serial.printf("Failed Node-%d, Response Code: ", index);
    Serial.print(result, HEX);
    Serial.println("");
    delay(5000);
  }

  return reading;
}

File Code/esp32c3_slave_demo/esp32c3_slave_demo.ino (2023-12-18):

// To Run the RS485
#include <SoftwareSerial.h>  

// To Run Lora 
#include <SPI.h> 
#include <LoRa.h>

// RGB LED Control
#include <Adafruit_NeoPixel.h>

// To Package sensor data
#include <ArduinoJson.h>

// RS485 Configuration for NPK Sensor
#define sensorFrameSize 11
#define sensorWaitingTime 1000
#define sensorByteResponse 0x0E

//Lora SPI Pin configuration
#define SS 3
#define RST 2
#define DIO 6

//Data direction pin for RS485
const int dtr = 5;

// RS485 Byte Address Request to Sensor
unsigned char nReq[8] = { 0x01, 0x03, 0x00, 0x1E, 0x00, 0x01, 0xE4, 0x0C };  //Nitrogen
unsigned char pReq[8] = { 0x01, 0x03, 0x00, 0x1F, 0x00, 0x01, 0xB5, 0xCC };  //Phosporous
unsigned char kReq[8] = { 0x01, 0x03, 0x00, 0x20, 0x00, 0x01, 0x85, 0xC0 };  //Potassium

unsigned char byteResponse[11] = {};

unsigned long lastSensorRead = 0;

uint8_t R = 0;
uint8_t G = 0;
uint8_t B = 0;

SoftwareSerial sensor(4, 7);
Adafruit_NeoPixel pixels(1, 19, NEO_GRB + NEO_KHZ800);

StaticJsonDocument<96> doc;

void setup() {
  // put your setup code here, to run once:
  Serial.begin(115200);
  sensor.begin(9600);

  pinMode(dtr, OUTPUT);
  digitalWrite(dtr, LOW);

  if (!sensor) {  // If the object did not initialize, then its configuration is invalid
    Serial.println("Invalid pin configuration, check config");
    while (1) {  // Don't continue with invalid configuration
      delay(1000);
    }
  }

  pixels.begin();
  pixels.clear();

  LoRa.setPins(SS, RST, DIO);  // set CS, reset, IRQ pin

  if (!LoRa.begin(868E6)) {  // initialize ratio at 868 MHz
    Serial.println("LoRa init failed. Check your connections.");
    while (true)
      ;  // if failed, do nothing
  }
}

void loop() {

  //Get the sensor value every 15secs  and send it through lora
  if (millis() - lastSensorRead >= 15000) {
    
    String packagedData = "";
    
    R = random(256);
    G = random(256);
    B = random(256);

    Serial.println("Setting the color of RGB LED");
    Serial.printf("The Value of R: %d G: %d B: %d",R,G,B);
    Serial.println();

    pixels.setPixelColor(0, pixels.Color(R, G, B));
    pixels.show();  // Send the updated pixel colors to the hardware.


    float N = getSensorValue(nReq);
    float P = getSensorValue(pReq);
    float K = getSensorValue(kReq);

    Serial.printf("Sensor Value, N: %f P : %f K : %f",N,P,K);
    
    //Package all the data 

    doc["N"] = N;
    doc["P"] = P;
    doc["K"] = K;
    doc["R"] = R;
    doc["G"] = G;
    doc["B"] = B;

    serializeJson(doc, packagedData);
    
    Serial.println("Sending data through Lora!");
    Serial.println(packagedData);

    LoRa.beginPacket();
    LoRa.print(packagedData);
    LoRa.endPacket();

    lastSensorRead = millis();
  }
}

float getSensorValue(unsigned char req[]) {
  //request reading from the sensor
  sensor.flush();
  digitalWrite(dtr, HIGH);
  sensor.write(req, 8);
  digitalWrite(dtr, LOW);

  // Wait for sensor to response
  unsigned long resptime = millis();
  while ((sensor.available() < sensorFrameSize) && ((millis() - resptime) < sensorWaitingTime)) {
    delay(1);
  }

  while (sensor.available()) {
    for (int n = 0; n < sensorFrameSize; n++) {
      byteResponse[n] = sensor.read();
      delay(1);
    }
  }

  //Print the byte response!
  for (int i = 0; i < 7; i++) {
    Serial.print(byteResponse[i], HEX);
    Serial.print(" ");
  }

  float combined_value = 0.0;
  //Convert Hex value to Decimal
  if (byteResponse[2] == 0x02) {
    combined_value = (byteResponse[3] << 8) | byteResponse[4];
    Serial.println("calculating 2 byte response");
  } else if (byteResponse[2] == 0x04) {
    combined_value = (byteResponse[5] << 8) | byteResponse[6];
    Serial.println("calculating 4 byte response");
  }

  for (int i = 0; i < 11; i++) {
    byteResponse[i] = 0;
  }

  Serial.println("Value : " + String(combined_value));
  return combined_value;
}

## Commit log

2023-12-18 updated cad images
2023-12-24 Update README.md
    Updated component -> schematic design video link
2024-01-07 Update README.md
    Updated PCB Layout Video Link
2025-07-02 Completed the repo 1. Added the kicad files for the master & slave node 2. Updated readme with the latest links
    [Environmental_monitoring_device.kicad_pcb, Environmental_monitoring_device.kicad_sch, environment slave.kicad_pcb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]
2025-07-05 resolves issue #1
    [Environmental_monitoring_device.kicad_pcb, Environmental_monitoring_device.kicad_sch, environment slave.kicad_pcb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]
